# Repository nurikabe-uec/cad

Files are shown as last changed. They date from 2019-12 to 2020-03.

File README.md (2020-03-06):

# cad
ピン作成時に使用する 3Dプリンタで作成する部品の cad データ
3Dプリンタの精度によって印刷できない場合 (穴があかないなど) があったため, 少しパラメータを変えた stl ファイルがたくさんあるという
git とは？というファイルの分け方をしている.

## motor_joint_for_milling

- 最新版は motor_joint_for_milling_top040mm_080slit.stl
- 現在のところ, 使用する予定のモータをネジを接合する部品
- ネジを回しながら挿入し固定する (milliing みたいに)

## photon がついてるファイル

- 梶本研の光造形 photon 用のファイル

## motor_joint_*slit.stl

- インサートナットを入れるように作成していたもの
- スリットが3Dプリンタで上手く作れなかったので無限にトライ&エラーした痕跡がある
- インサートナットはまっすぐ入れるのが難しかったのでやめた.

## motor_cover.stl

- モータを壁につけるやつ

## jikuuke.stl

- どれが最終版だかわからなくなってしまった...

## motor_and_pin_joint 

- プラスチックの底の装着する部品
- ナットを入れて, ネジで上下させるためのもの

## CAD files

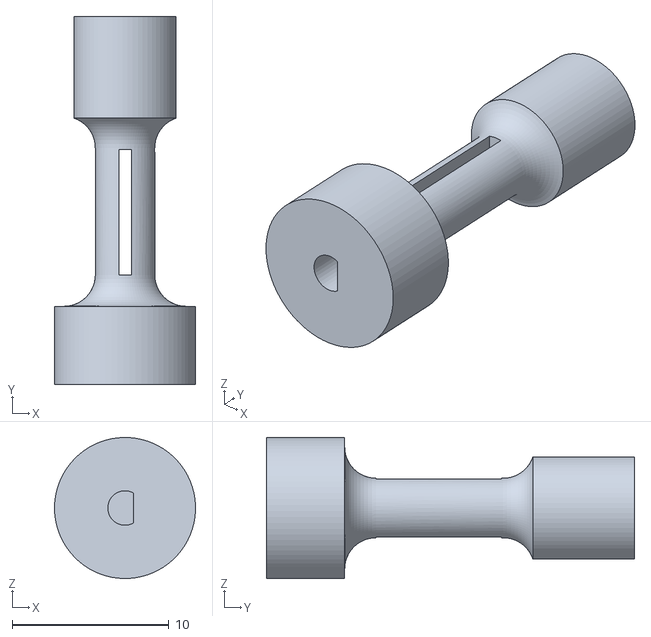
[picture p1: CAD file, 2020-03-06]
motor_joint_for_milling_top040mm_080slit.stl
9.00 x 23.5 x 9.00

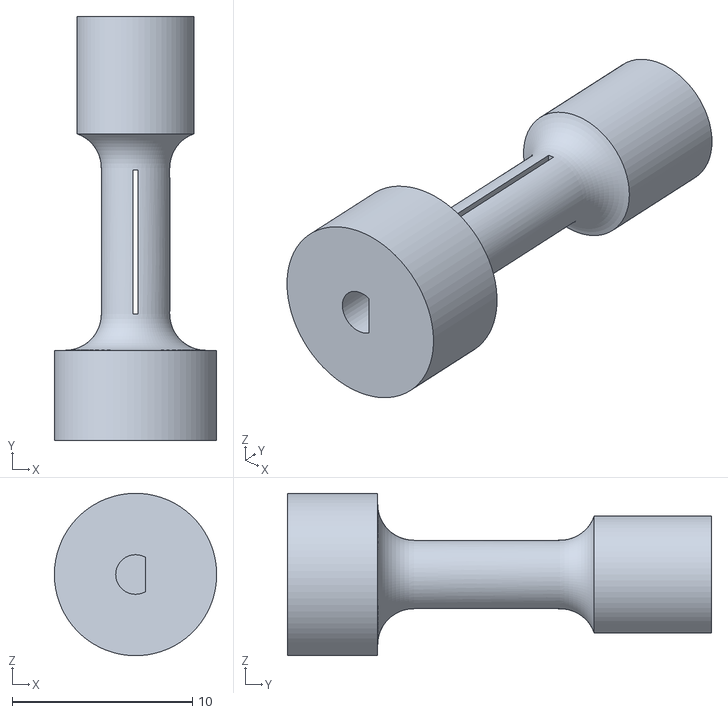
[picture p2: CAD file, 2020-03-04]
motor_joint_for_milling_top039mm.stl
9.00 x 23.5 x 9.00

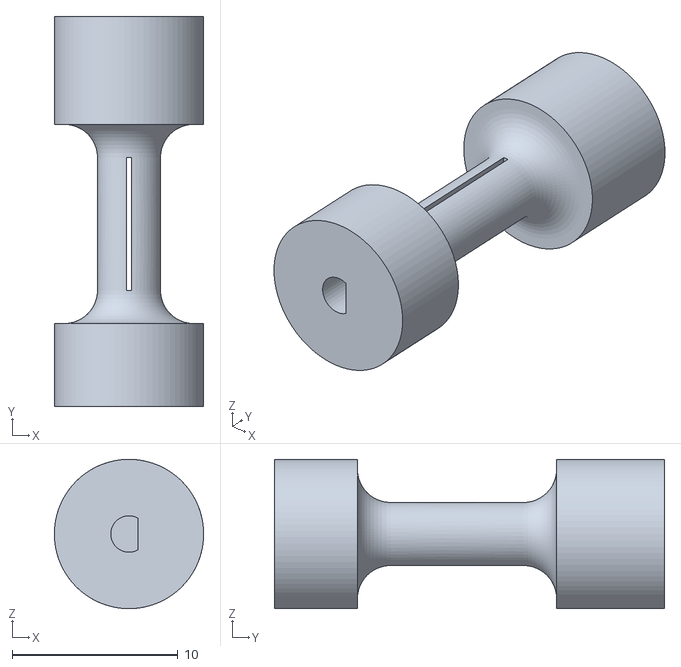
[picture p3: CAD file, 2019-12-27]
motor_joint_030slit_22mm.stl
9.00 x 23.5 x 9.00

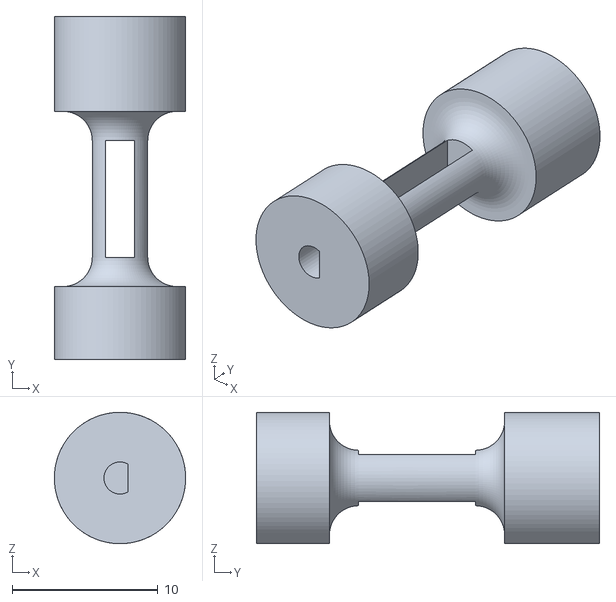
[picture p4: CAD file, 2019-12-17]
motor_joint_200slit_2.stl
9.00 x 23.5 x 9.00

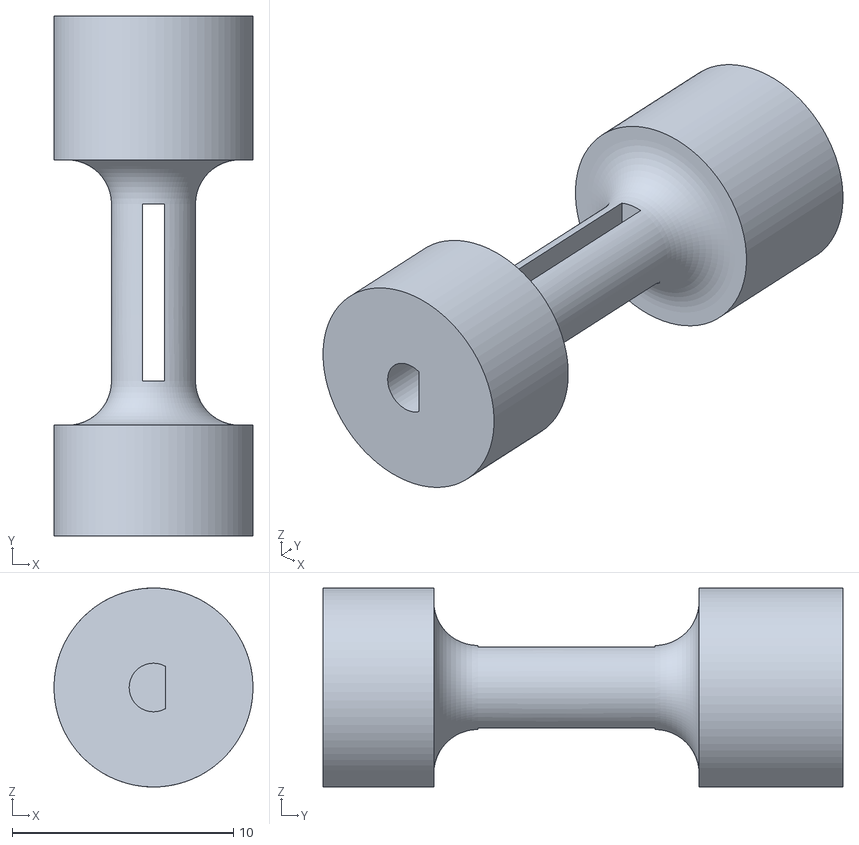
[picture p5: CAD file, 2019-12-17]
motor_joint_100slit_22mm.stl
9.00 x 23.5 x 9.00

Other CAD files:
motor_joint_for_milling_top040mm.stl
motor_joint_for_milling_top038mm.stl
motor_joint_020slit_21mm.stl
motor_joint_040slit_22mm.stl
motor_joint_100slit_21mm.stl
motor_joint_180slit.stl
motor_joint_150slit_22mm.stl
motor_joint_050slit_21mm.stl
motor_joint_020slit_22mm.stl
motor_joint_200slit.stl
motor_joint_175slit.stl
motor_joint_05slit.stl
motor_joint_050slit.stl
OldVersions/pin_joint_plastic_ver1.0001.ipt
jikuuke_ver2.ipt
jikuuke_ver2_7_5mm.stl
jikuuke_ver2_7_7mm.stl
motor_and_pin_joint.ipt
motor_and_pin_joint_m4.stl
motor_cover.ipt
motor_joint.ipt
motor_joint.stl
motor_joint_075slit.stl
motor_joint_100slit.stl
motor_joint_125slit.stl
motor_joint_150slit.stl
motor_joint_15slit.stl
motor_joint_1slit.stl
motor_joint_4-1mm.stl
motor_joint_direct_screw.stl
motor_joint_for_insert_nut.stl
motor_joint_for_milling.ipt
motor_joint_for_photon.ipt
motor_joint_for_photon.stl
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

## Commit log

2019-10-11 add pin_joint_plastic_ver2
    [pin_joint_plastic_ver2.ipt]
2019-10-14 プラスチックピンをまた印刷してみた
    [pin_joint_plastic_v3.ipt, pin_joint_ver5_for_plstc_0940.stl, pin_joint_ver5_for_plstc_0945.stl]
2019-10-14 motor と ネジのジョイントを作っています
    [motor_and_pin_joint.ipt]
2019-10-14 [2019/10/14] 今印刷しているやつ，失敗するかも どうなることやら...
    [motor_and_pin_joint_m4.stl]
2019-10-18 インサートナットを入れるように変更
    [motor_joint.0019.ipt, motor_joint.ipt, motor_joint.stl]
2019-10-25 - 4mm 穴をあけるように変更 - 積層と光造形とで精度が違うのでモデルを分ける
    [motor_joint.0019.ipt, motor_joint.0020.ipt, motor_joint.ipt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]
2019-10-25 [PHOTON] 2個所修正 - フォトインタラプタに挟めるように一部細く - インサートナットをいれられるように穴の径を広げた
    [motor_joint_for_photon.0021.ipt, motor_joint_for_photon.ipt, motor_joint_for_photon.stl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]
2019-11-01 変更 - フォトインタラプタ挟めるように - 光造形と積層で分ける - 細すぎた
    [motor_joint.0020.ipt, motor_joint.ipt, motor_joint_direct_screw.stl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]
2019-11-25 motor joint 変更
    [motor_joint.ipt, motor_joint_for_insert_nut.stl, motor_joint_for_photon.ipt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]
2019-11-25 ねじ穴ナット穴リサイズ（あとはピンの入る溝）
    [pin_joint_plastic_v4.ipt]
2019-11-25 motor とpin のジョイントを光造形用に修正(motor_joint_for_photon) 軸受けをベアリングが抜けないように少し細く(jikuuke) ピンを挿すジョイントの溝を少し広げた(pin_joint_plastic)
    [jikuuke_ver2.ipt, jikuuke_ver2_7_5mm.stl, jikuuke_ver2_7_7mm.stl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]
2019-12-02 motor とピンのジョイント(photon用) とピン挿すやつ
    [motor_joint_for_photon.ipt, motor_joint_for_photon_insertnut.stl, pin_joint_plastic_v4.ipt]
2019-12-02 少し細すぎたので太くした
    [motor_joint_for_photon_thick.stl]
2019-12-10 3Dプリンタ用にスリッドをあけたもの
    [motor_joint_05slit.stl, motor_joint_075slit.stl, motor_joint_125slit.stl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]
2019-12-10 ピクトの3Dプリンタでは穴が開かなかったので，少し広げた
    [motor_joint.ipt, motor_joint_175slit.stl]
2019-12-10 念のためにさらにスリットを広げたバージョン
    [motor_joint.ipt, motor_joint_200slit.stl]
2019-12-17 試行錯誤の後
    [motor_joint.ipt, motor_joint_020slit_21mm.stl, motor_joint_020slit_22mm.stl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]
2019-12-27 millingするように
    [motor_joint.ipt, motor_joint_030slit_22mm.stl, motor_joint_for_milling.ipt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]
2020-03-04 milling version 2 (少し径を広げた)
    [motor_joint_for_milling.ipt, motor_joint_for_milling_top039mm.stl, motor_joint_for_milling_top040mm.stl]
2020-03-06 motor_joint ネジをねじこむタイプスリットを少し広げた (0.3~5mm ではスリットが開かなかったため
    [motor_joint_for_milling.ipt, motor_joint_for_milling_top040mm_080slit.stl]
